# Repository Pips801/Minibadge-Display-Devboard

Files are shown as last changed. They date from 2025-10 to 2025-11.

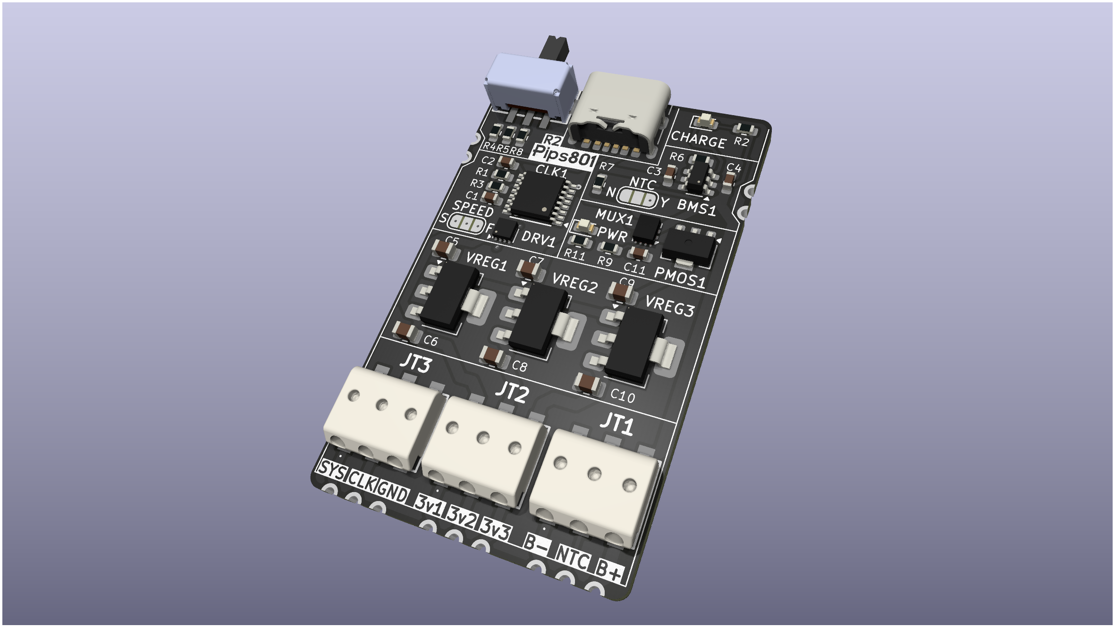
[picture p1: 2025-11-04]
Pictures/render2.png

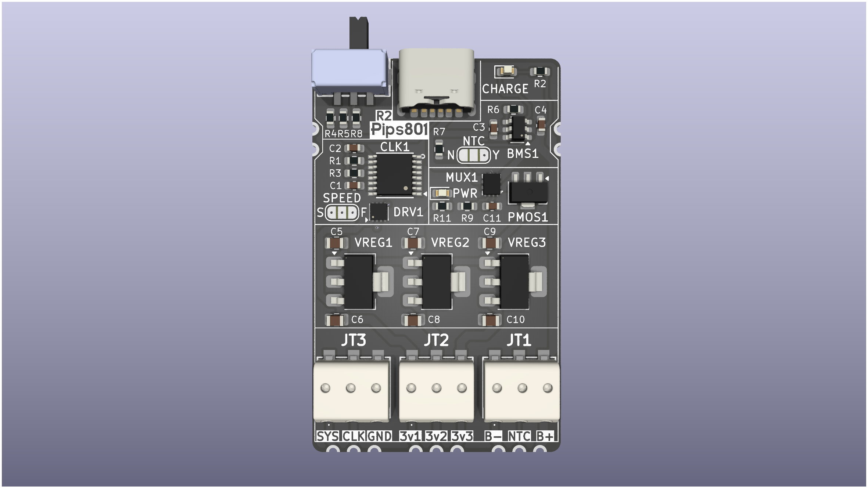
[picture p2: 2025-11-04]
Pictures/render1.png

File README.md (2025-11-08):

# Minibadge Display Devboard
A small PCB that allows you to create your own Minibadge displays!

This board provides everything your custom Minibadge display will need, including LiPo battery charging/use and USB-C power. It can be attached board-to-board with your own PCB designs, or it can be wired up using push-in WAGO wire terminals to your existing displays.

 

## Datasheets
* Voltage regulator - TLV62585RWT - https://www.ti.com/lit/ds/symlink/tlv62585.pdf
* Battery management system - BQ21040 - https://www.ti.com/lit/ds/symlink/bq21040.pdf
* Clock generator - 74HC4060 - https://assets.nexperia.com/documents/data-sheet/74HC_HCT4060.pdf
* Clock driver - DRV8837C - https://www.ti.com/lit/ds/symlink/drv8837c.pdf
* Powepath MUX - TPS2121 - https://www.ti.com/lit/ds/symlink/tps2121.pdf

# Specifications
* Provides your Minibadges battery or USB-C power, 3.3v@3A, CLK, GND, and VBATT.
* Supports LiPo batteries, optionally with NTC temp sensors.
  * 2x LiPo batteries of matching composition, mAh, and charge state can be wired in parallel.
  * 800mA battery charging.
* Features castellated edge-mount pads for direct board to board connections.
* Features WAGO PCB terminal blocks for custom wiring.
* Power switch disconnects minibadges while still powering the battery charging circuit.
* Solderable jumper for disabling temp sensor and selecting CLK speed.

# Limitations
* Input (USB-C): 5V@3A
* Input (Battery): 4.2V@3A
* Battery charging: 4.2V@800mA
* Output (3.3V): 3.3V@3A
* Output (CLK): 3.3V@3A
* Output (SYS): Input voltage@amperage (whichever is higher)
* Max total minibadges: 30-50

# Revisions

R2 Update list
* Better thermal management for voltage regulators under load.
* Updated PMIC ORing power path chip, replacing dual ORing diodes.
* Updated PFET for power on/off switching and system load capacity.
* Better thermal management for PFET under load.
* Improved current flow and reduced waste heat for CLK driver.
* Thicker power traces for 3.3v regulators and Battery.
* Updated silkscreen component markers.
* Updated solder paste for stronger on/off switch mounting.

R3 Update list
* Larger castellated pads for better connection.
* Addition of a second row of pads for pins.
* Swap from 3x LDO regulators to 1x Buck regulator.
* Decreased waste heat and better thermal management.
* Shrunk board height by 2.54mm.
* Added technical limitations on silkscreen.

# Designing a Minibadge display
### Setup
* Import Minibadge footprints and symbols into KiCad.
* Import DevBoard footprint and symbol into KiCad.

### Schematic
* Create schematic with as many minibadges as you want.
* Import the Devboard symbol and wire up CLK, GND, and SYS (VBATT/5V).
* Wire up the minibadges 3.3v lines.



### PCB
* Arrange all of your minibadges.
* Finalize your board shape.
* Place the Devboard on the back of the PCB with the USB port against the edge of your board.
* Wire up your CLK, GND, 3x 3.3v, and SYS (VBATT/5V)

 

# Assembly
1. Solder the `SPEED` jumper to select the Clock frequency. F for Fast, S for Slow.
2. Solder or attach (through the WAGO) your battery positive and negative leads.
3. If your battery has an NTC temperature wire (third wire, usually white or yellow) connect it to the NTC pad or terminal. Solder the `NTC` jumper to `Y` (Yes NTC)
4. If your battery does not have an NTC temperature wire, solder the `NTC` jumper to the `N` (No NTC) position.
5. Solder or wire up your 3 different 3.3v lines from your display board.
6. Solder or wire up GND, SYS (VBATT/5V), and CLK to the appropriate connections on your display.

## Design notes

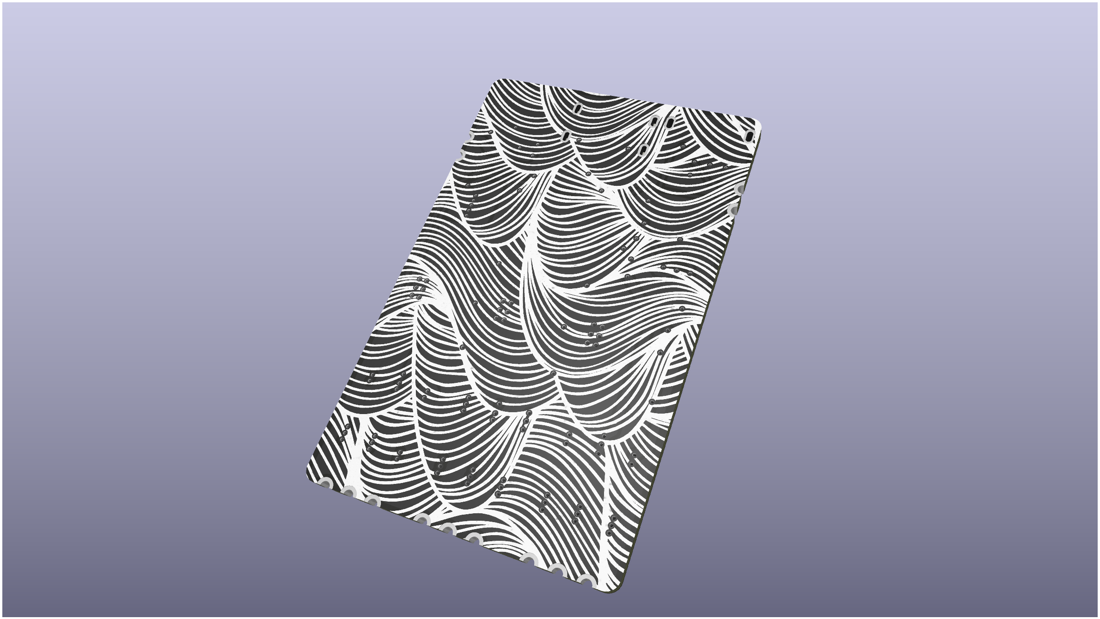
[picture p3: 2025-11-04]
Pictures/render3.png

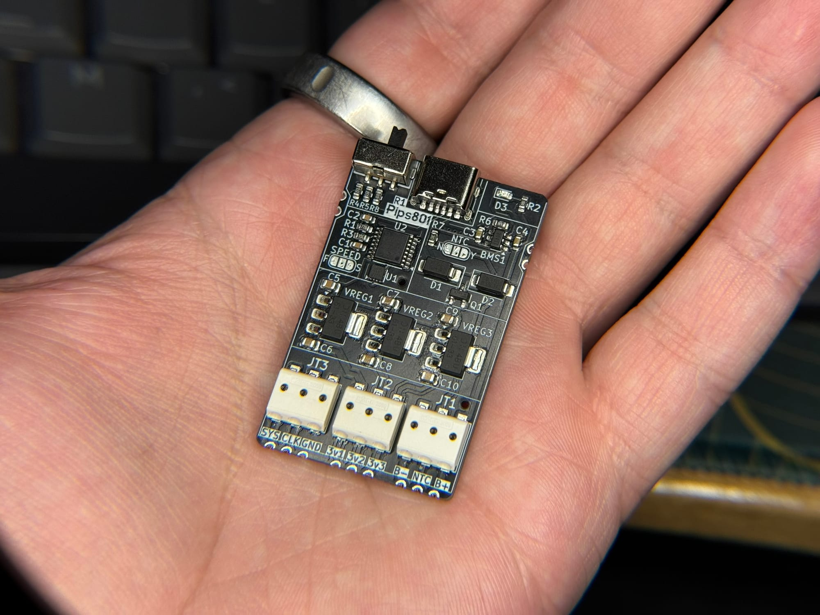
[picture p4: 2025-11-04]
Pictures/handheld.png

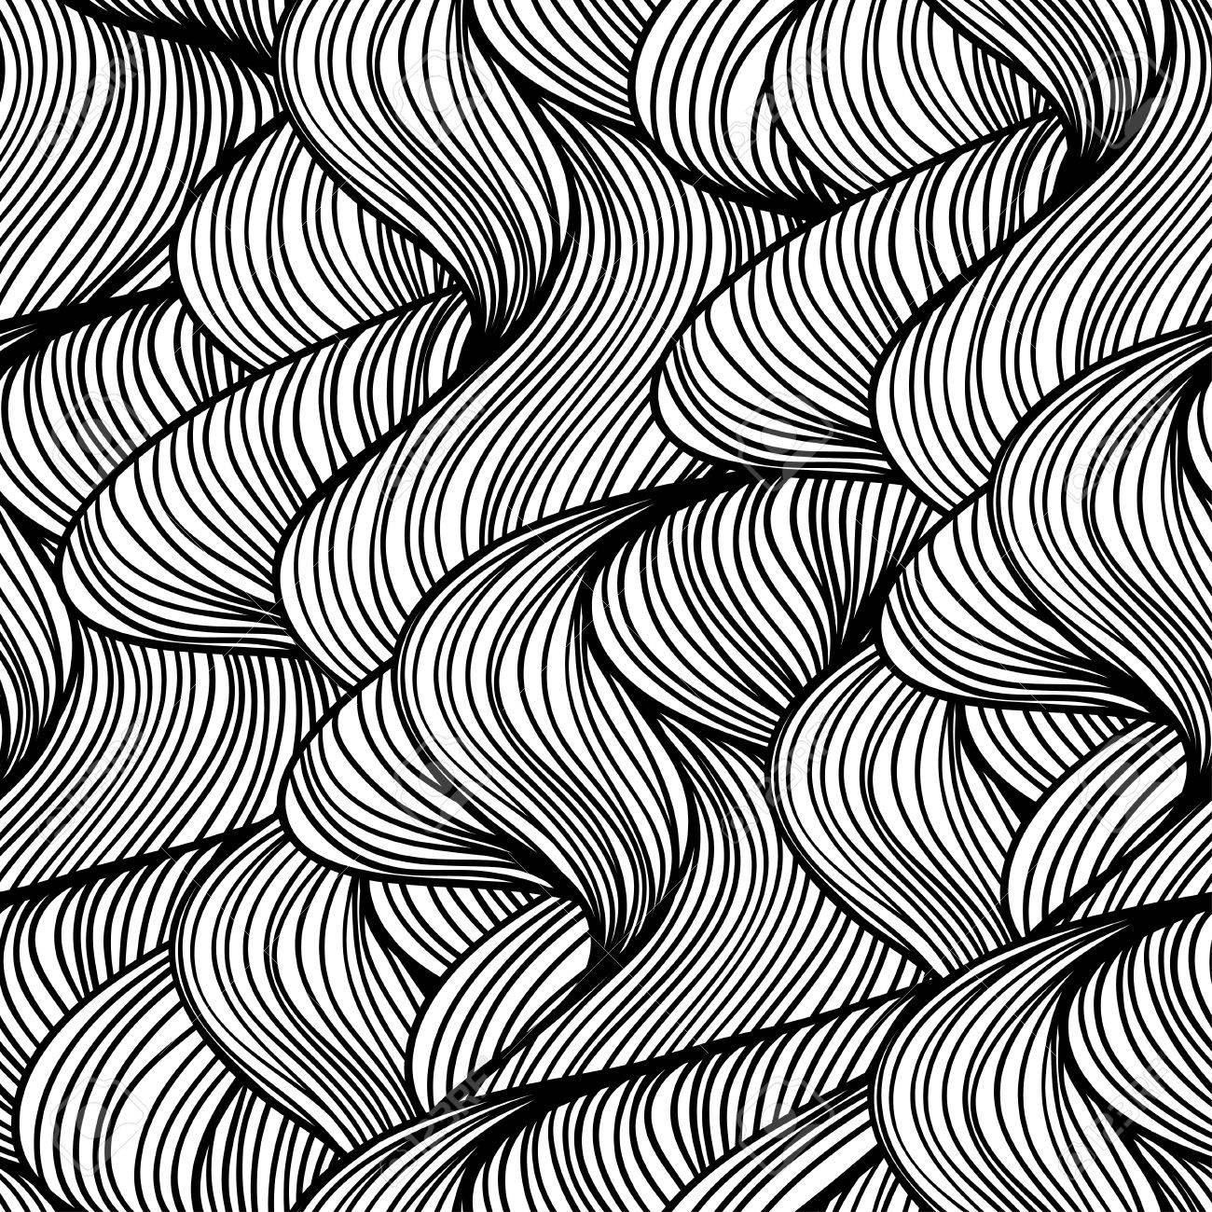
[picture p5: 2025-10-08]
wave pattern 1.jpg

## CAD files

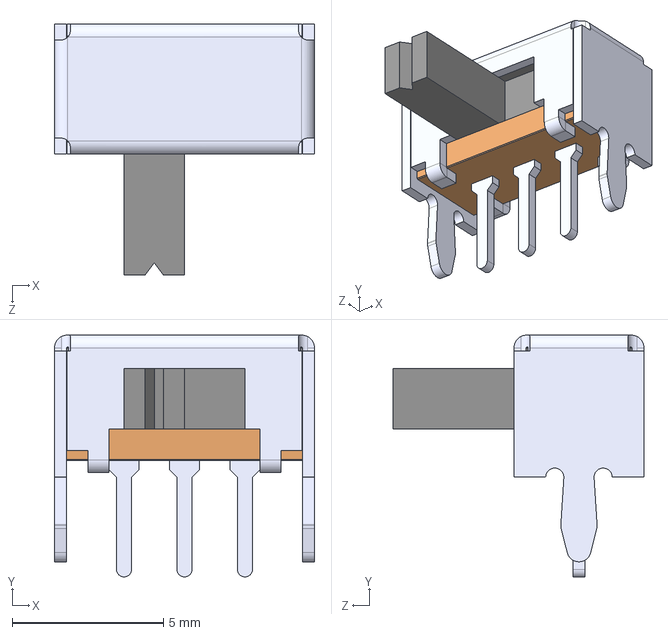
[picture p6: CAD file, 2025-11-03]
Components/SK12D07VG3-T/SK12D07VG4--3DModel-STEP-269445.STEP
8.60 x 8.00 x 8.30 mm

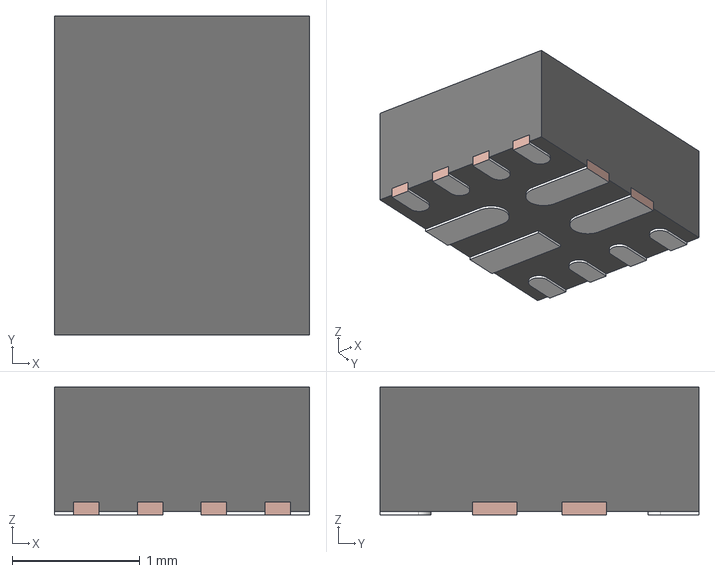
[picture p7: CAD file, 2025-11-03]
Components/TPS2121/RUX0012A.stp
2.00 x 2.50 x 1.00 mm
FRAME
MOLD

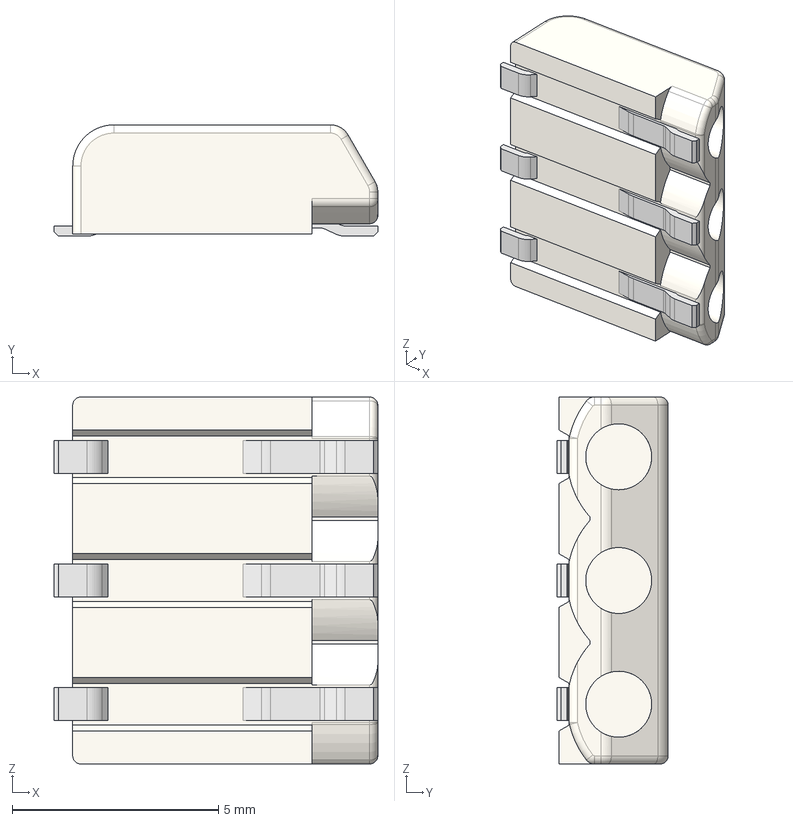
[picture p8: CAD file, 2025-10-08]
Components/WAGO 2059-303/2059-303_998-403.stp
7.85 x 2.70 x 8.90 mm

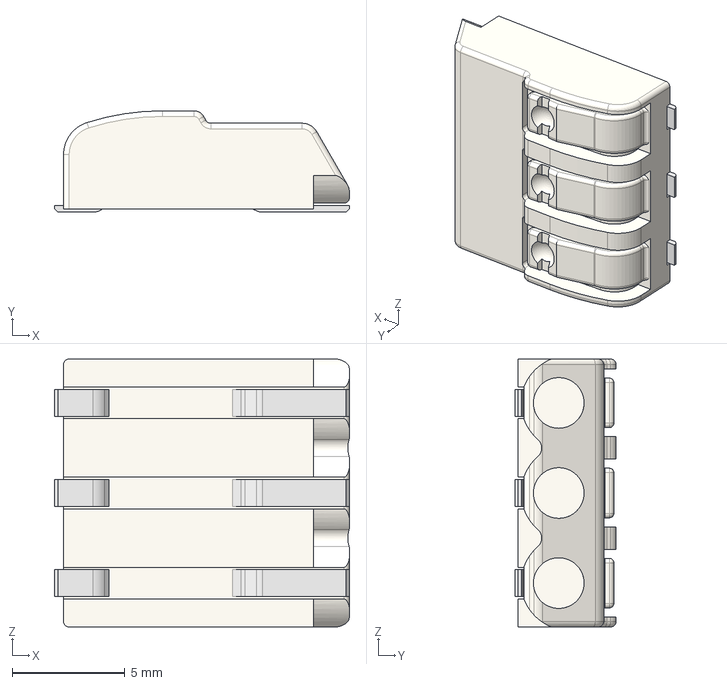
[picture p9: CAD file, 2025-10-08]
Components/WAGO 2060-453/2060-453_998-404.stp
13.1 x 4.50 x 11.9 mm

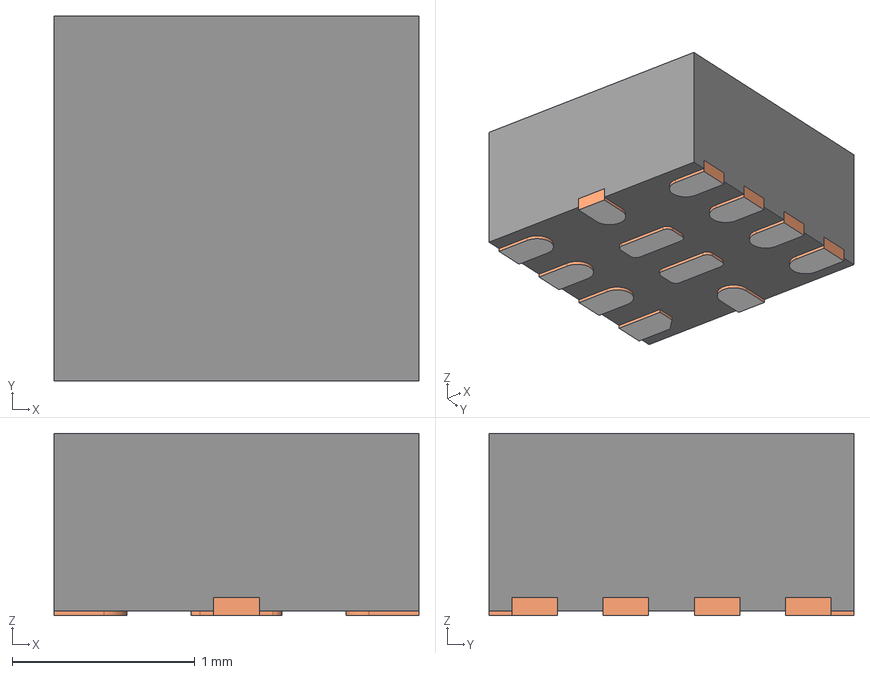
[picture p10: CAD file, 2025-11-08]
Components/TLV62585RWTR/TLV62585RWTR.stp
2.00 x 2.00 x 1.00 mm
BODY-QFN
FRAME-RWT0012A
PIN1-ID

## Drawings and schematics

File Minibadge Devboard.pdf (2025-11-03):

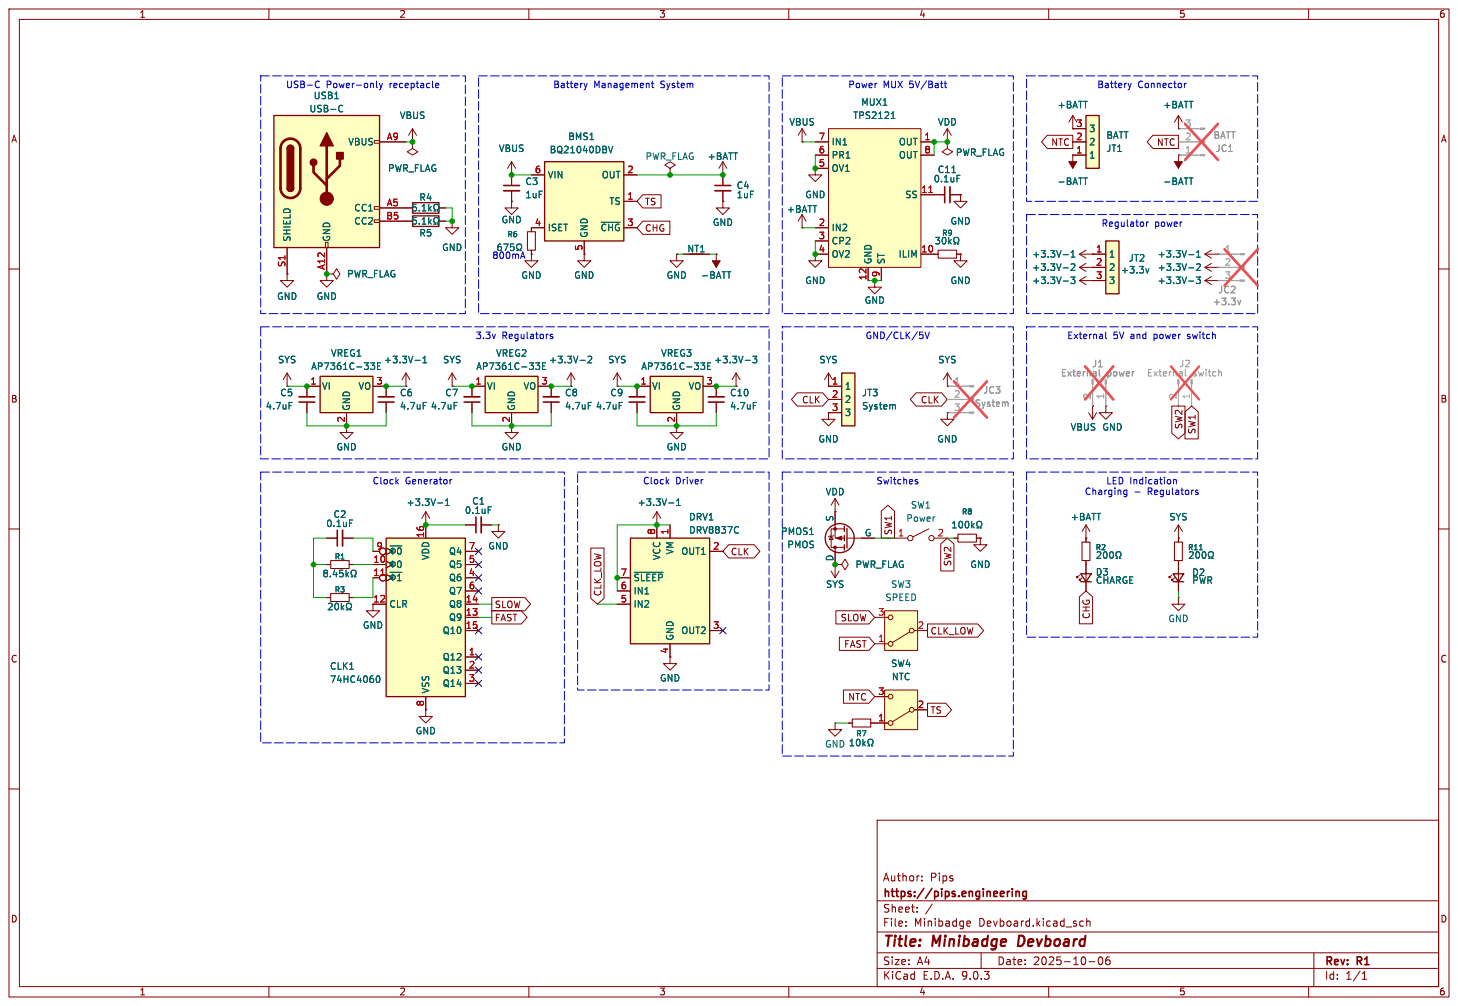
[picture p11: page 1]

Id: 1/1 Title: Minibadge Devboard

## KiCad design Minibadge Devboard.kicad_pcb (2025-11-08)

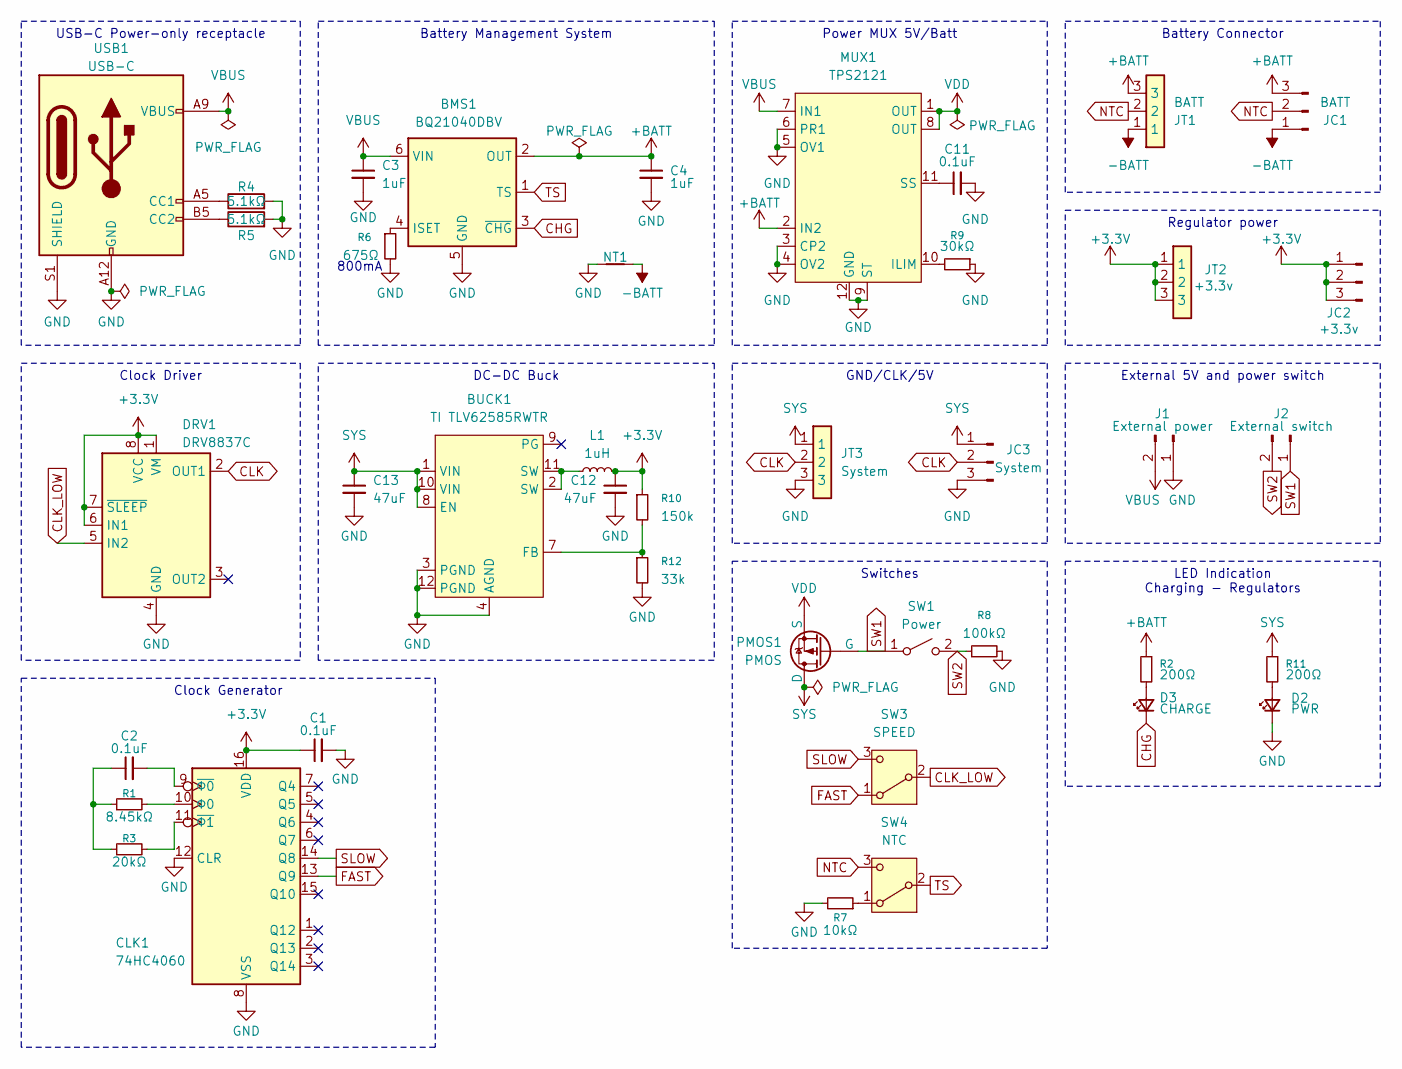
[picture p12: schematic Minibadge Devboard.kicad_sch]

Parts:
BMS1: BQ21040DBV; SOT-23-6; LCSC Part # C202311
BUCK1: TI TLV62585RWTR; TLV62585RWTR; LCSC Part # C406872
C1, C2, C11: 0.1uF; C_0603_1608Metric; LCSC Part # C14663
C3, C4: 1uF; C_0603_1608Metric; LCSC Part # C15849
C12, C13: 47uF; C_1206_3216Metric; LCSC Part # C96123
CLK1: 74HC4060; TSSOP-16-1EP_4.4x5mm_P0.65mm; LCSC Part # C354054
D2: PWR; LED_0603_1608Metric; LCSC Part # C2286
D3: CHARGE; LED_0603_1608Metric; LCSC Part # C2286
DRV1: DRV8837C; WSON-8-1EP_2x2mm_P0.5mm_EP0.9x1.6mm; LCSC Part # C191000
J1: External power; Castellated pins 1x02
J2: External switch; Castellated pins 1x02
JC1: BATT; Castellated pins 1x03
JC2: +3.3v; Castellated pins 1x03
JC3: System; Castellated pins 1x03
JT1: BATT; 2059-303; Manufacturer_Part_Number 2060-453/998-404; LCSC Part # C3309252
JT2: +3.3v; 2059-303; Manufacturer_Part_Number 2060-453/998-404; LCSC Part # C3309252
JT3: System; 2059-303; Manufacturer_Part_Number 2060-453/998-404; LCSC Part # C3309252
L1: 1uH; L_KOHERelec_MDA5030; LCSC Part # C2847474
MUX1: TPS2121; Texas_VQFN-HR-12_2x2.5mm_P0.5mm; LCSC Part # C485916
NT1: NetTie_2; NetTie-2_SMD_Pad2.0mm
PMOS1: PMOS; SOT-89-3; LCSC Part # C19272814
R1: 8.45kΩ; R_0603_1608Metric; LCSC Part # C25981
R2, R11: 200Ω; R_0603_1608Metric; LCSC Part # C8218
R3: 20kΩ; R_0603_1608Metric; LCSC Part # C4184
R4, R5: 5.1kΩ; R_0603_1608Metric; LCSC Part # C23186
R6: 675Ω; R_0603_1608Metric; LCSC Part # C23228
R7: 10kΩ; R_0603_1608Metric; LCSC Part # C25804
R8: 100kΩ; R_0603_1608Metric; LCSC Part # C25803
R9: 30kΩ; R_0603_1608Metric; LCSC Part # C22984
R10: 150k; R_0603_1608Metric; LCSC Part # C22807
R12: 33k; R_0603_1608Metric; LCSC Part # C4216
SW1: Power; SW-SMD_SK12D07VG3-T; LCSC Part # C25168821
SW3: SPEED; SolderJumper-3_P1.3mm_Open_RoundedPad1.0x1.5mm_NumberLabels; LCSC Part # C5149822
SW4: NTC; SolderJumper-3_P1.3mm_Open_RoundedPad1.0x1.5mm_NumberLabels; LCSC Part # C5149822
USB1: USB-C; USB_C_Receptacle_HRO_TYPE-C-31-M-17; LCSC Part # C283540

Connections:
+3.3V: C1.1, C12.1, CLK1.16 (VDD), DRV1.1 (VM), DRV1.6 (IN1), DRV1.7 (~SLEEP), DRV1.8 (VCC), JC2.1, JC2.2, JC2.3, JT2.1, JT2.2, JT2.3, L1.2, R10.1
+BATT: BMS1.2 (OUT), C4.1, JC1.3, JT1.3, MUX1.2 (IN2), R2.1
-BATT: JC1.1, JT1.1, NT1.2
CHG: BMS1.3 (~CHG), D3.1 (K)
CLK: DRV1.2 (OUT1), JC3.2, JT3.2
CLK_LOW: DRV1.5 (IN2), SW3.2 (B)
FAST: CLK1.13 (Q9), SW3.1 (A)
GND: BMS1.5 (GND), BUCK1.3 (PGND), BUCK1.4 (AGND), BUCK1.12 (PGND), C1.2, C3.2, C4.2, C11.2, C12.2, C13.2, CLK1.8 (VSS), CLK1.12 (CLR), D2.1 (K), DRV1.4 (GND), DRV1.9 (GND), J1.1, JC3.3, JT3.3, MUX1.3 (CP2), MUX1.4 (OV2), MUX1.5 (OV1), MUX1.6 (PR1), MUX1.9 (ST), MUX1.12 (GND), NT1.1, R4.2, R5.2, R6.2, R7.2, R8.2, R9.1, R12.2, USB1.A12 (GND), USB1.B12 (GND), USB1.S1 (SHIELD)
NTC: JC1.2, JT1.2, SW4.3 (C)
unnamed: BMS1.4 (ISET), R6.1
unnamed: BUCK1.7 (FB), R10.2, R12.1
unnamed: BUCK1.2 (SW), BUCK1.11 (SW), L1.1
unnamed: C2.1, R1.1, R3.1
unnamed: C2.2, CLK1.9 (~Φ0)
unnamed: CLK1.11 (~Φ1), R3.2
unnamed: CLK1.10 (Φ0), R1.2
unnamed: D2.2 (A), R11.2
unnamed: D3.2 (A), R2.2
unnamed: MUX1.10 (ILIM), R9.2
unnamed: C11.1, MUX1.11 (SS)
unnamed: R7.1, SW4.1 (A)
unnamed: R4.1, USB1.A5 (CC1)
unnamed: R5.1, USB1.B5 (CC2)
SLOW: CLK1.14 (Q8), SW3.3 (C)
SW1: J2.1, PMOS1.1 (G), SW1.1 (A)
SW2: J2.2, R8.1, SW1.2 (B)
SYS: BUCK1.1 (VIN), BUCK1.8 (EN), BUCK1.10 (VIN), C13.1, JC3.1, JT3.1, PMOS1.2 (D), R11.1
TS: BMS1.1 (TS), SW4.2 (B)
VBUS: BMS1.6 (VIN), C3.1, J1.2, MUX1.7 (IN1), USB1.A9 (VBUS), USB1.B9 (VBUS)
VDD: MUX1.1 (OUT), MUX1.8 (OUT), PMOS1.3 (S)

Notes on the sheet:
800mA
External 5V and power switch
USB-C Power-only receptacle
DC-DC Buck
Battery Connector
Battery Management System
Power MUX 5V/Batt
LED Indication Charging - Regulators
GND/CLK/5V
Switches
Clock Driver
Clock Generator
Regulator power

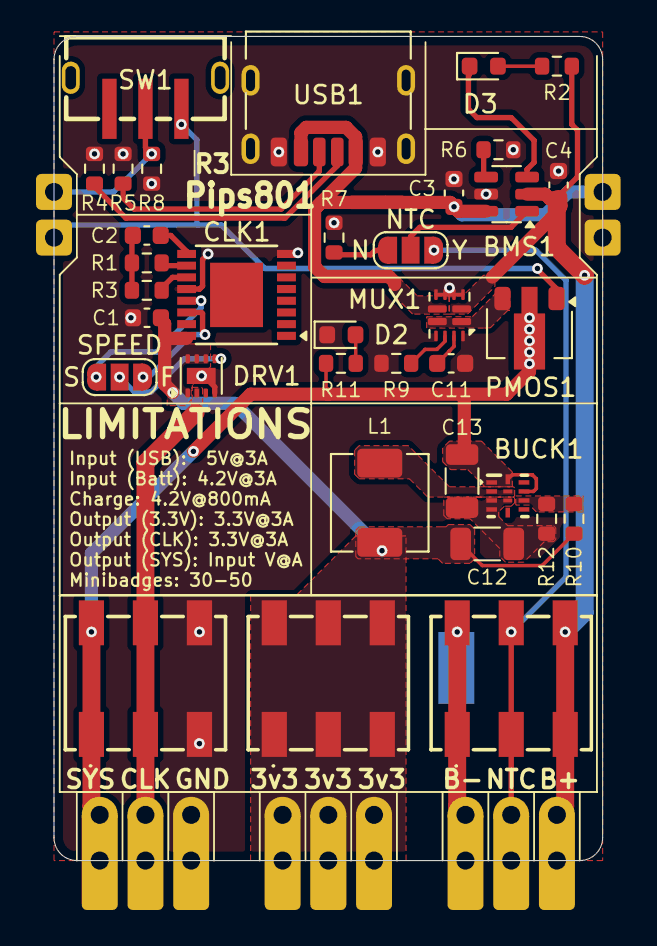
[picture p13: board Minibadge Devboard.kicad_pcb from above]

Board: 2 copper layers, 30.5 x 45.8 mm, 41 parts (1 on the bottom side), 30 nets.

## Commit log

2025-10-07 add WAGO connector library
2025-10-07 Schematic PDF
2025-10-07 Add WAGO 2059 for smaller footprint
    [Minibadge Devboard.kicad_sch]
2025-10-07 layout updates
    [Minibadge Devboard.kicad_pcb]
2025-10-07 update footprints
    [Minibadge Devboard.kicad_sch]
2025-10-07 Update Minibadge Devboard.kicad_pcb
    [Minibadge Devboard.kicad_pcb]
2025-10-08 Add Footprint and Symbol
    [Minibadge Devboard.kicad_pcb]
2025-10-08 Silkscreen fixes and thermal via stitching/anchoring
    [Minibadge Devboard.kicad_pcb]
2025-10-08 Add support for external PSU and Power switch
    [Minibadge Devboard.kicad_pcb, Minibadge Devboard.kicad_sch]
2025-10-08 update symbol for external power and switch
2025-10-09 BOM updates
    [Minibadge Devboard.kicad_pcb, Minibadge Devboard.kicad_sch]
2025-10-10 LCSC part numbers
    [Minibadge Devboard.kicad_pcb, Minibadge Devboard.kicad_sch]
2025-10-15 Fixes
    * Added text to the footprint to clarify which castellated pin is what
    * Fixed pinout issue with footprint and symbol. SYS and GND were reversed (yikes)
    * Updated schematic symbols and values
    * push updated schematic PDF
    [Minibadge Devboard.kicad_pcb, Minibadge Devboard.kicad_sch]
2025-10-19 no thermal reliefs
    [Minibadge Devboard.kicad_pcb]
2025-10-19 Copper plane for CLK driver power
    [Minibadge Devboard.kicad_pcb]
2025-10-19 Thermal vias for VREG
    [Minibadge Devboard.kicad_pcb, Minibadge Devboard.kicad_sch]
2025-10-19 Via tenting
    [Minibadge Devboard.kicad_pcb]
2025-10-19 small fixes
    [Minibadge Devboard.kicad_pcb]
2025-10-19 Swap to TPS2121 for ORing powerpath
    [Minibadge Devboard.kicad_pcb, Minibadge Devboard.kicad_sch]
2025-10-19 minor fixes
    [Minibadge Devboard.kicad_pcb]
2025-10-19 Upgrade power switching FET
    [Minibadge Devboard.kicad_pcb, Minibadge Devboard.kicad_sch]
2025-10-19 update positioning and reference designators for silk
    [Minibadge Devboard.kicad_pcb, Minibadge Devboard.kicad_sch]
2025-10-19 Update schematic drawing
2025-10-19 Board stackup materials
    [Minibadge Devboard.kicad_pcb]
2025-10-19 Add STL
2025-10-26 Fix symbol
    [Minibadge Devboard.kicad_pcb, Minibadge Devboard.kicad_sch]
2025-10-30 Extend SW1 pads
    [Minibadge Devboard.kicad_pcb]
2025-10-30 longer pads for SW1
    [Minibadge Devboard.kicad_pcb]
2025-10-31 Fix PMIC copper fills
    [Minibadge Devboard.kicad_pcb]
2025-10-31 Adjust CC traces
    [Minibadge Devboard.kicad_pcb]
2025-10-31 Adjust BATT trace
    [Minibadge Devboard.kicad_pcb]
2025-10-31 Power switch mounting points on GND net
    should hopefully help with thermal transfer to mechanical points for better solder wicking
    [Minibadge Devboard.kicad_pcb]
2025-10-31 Add SYS thermal pour on underside of board for PMOS
    should help PMOS handle heat better
    [Minibadge Devboard.kicad_pcb]
2025-10-31 Trace fixes
    [Minibadge Devboard.kicad_pcb]
2025-10-31 Add solder paste in mechanical hole for SW1 and USB1
    [Minibadge Devboard.kicad_pcb]
2025-10-31 Thicker BATT trace
    [Minibadge Devboard.kicad_pcb]
2025-10-31 Wider solder paste layer on SW1
    [Minibadge Devboard.kicad_pcb]
2025-10-31 update paste layer again
    [Minibadge Devboard.kicad_pcb]
2025-11-01 Add more LEDs to schematic
    [Minibadge Devboard.kicad_sch]
2025-11-01 Add LCSC part numbers
    [Minibadge Devboard.kicad_sch]
2025-11-02 Indicators and silkscreen
    * Adjusted all passive component silkscreen thickness.
    * Added labels for batt charging and system power.
    * Added LED for system power.
    * Adjusted positioning for several components.
    * Swapped F and S CLK speed jumper text.
    * Removed CLK indicator (could not fit)
    [Minibadge Devboard.kicad_pcb, Minibadge Devboard.kicad_sch]
2025-11-02 Update Minibadge Devboard Schematic PDF
2025-11-02 Update Minibadge Devboard.kicad_pro
2025-11-02 Add 3d model for TPS2121
    [Minibadge Devboard.kicad_pcb, RUX0012A.stp]
2025-11-02 Add 3d model for switch
    [Minibadge Devboard.kicad_pcb, SK12D07VG4--3DModel-STEP-269445.STEP]
2025-11-02 update traces
    [Minibadge Devboard.kicad_pcb]
2025-11-02 Adjust traces
    [Minibadge Devboard.kicad_pcb]
2025-11-02 Fix power switch mounting hole net
    [Minibadge Devboard.kicad_pcb]
2025-11-03 Calculate ILIM and SS for MUX
    Added LCSC numbers for new parts as well
    [Minibadge Devboard.kicad_sch]
2025-11-03 Schematic changes
    [Minibadge Devboard.kicad_pcb, Minibadge Devboard.kicad_sch]
2025-11-03 Update values
    [Minibadge Devboard.kicad_pcb, Minibadge Devboard.kicad_sch]
2025-11-03 Update PDF for schematics
    [Minibadge Devboard.kicad_sch]
2025-11-08 Swap LDO to DC-DC
    [Minibadge Devboard.kicad_pcb, Minibadge Devboard.kicad_sch, TLV62585RWTR.stp]
2025-11-08 Implement/route DC-DC buck
    [Minibadge Devboard.kicad_pcb, Minibadge Devboard.kicad_sch]
2025-11-08 Update inductor
    [Minibadge Devboard.kicad_pcb, Minibadge Devboard.kicad_sch]

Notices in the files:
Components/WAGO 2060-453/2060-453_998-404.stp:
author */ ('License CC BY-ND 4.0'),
